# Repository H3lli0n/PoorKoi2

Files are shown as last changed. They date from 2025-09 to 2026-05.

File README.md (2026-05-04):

# PoorKoi2

Hi, HLB team Here !

In 2024 we ran our first public group-buy with the PoorKoi 1, an acrylic stacked keyboard. 30 happy users were very surprised by the clack of this simple 60% made with love. This was our first project, mistakes were made, but we learned a lot and we got confident that we could push even further: having the same thing in a cnc'd polycarbonate version!

We are aiming for the same clack and feeling with the polycarbonate version – with an affordable price. No brass weight or copper that are expensive if you don't sell 200 units. Simple design with references of the v1.

We had to make a stand between affordability and customization with a trusty and high quality manufacturer – DDS while upgrading our game : laser cut Poron gaskets, custom carrying case, in house hotswap pcb (as well as new solder one) !

You can find us on [Discord](https://discord.gg/ZV8Ysf6buB)

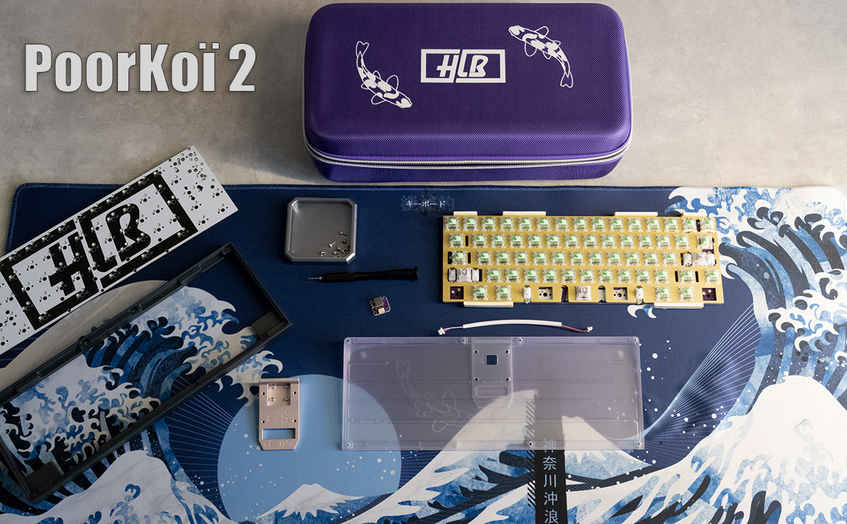
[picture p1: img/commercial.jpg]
PoorKoi 2


## Specifications
- 60% Poron gasket mount
- 7° typing angle
- WK/WKL/HHKB
- Polycarbonate bottom with central aluminium part
- Brass plate
- Geon feet D7
- 1.6mm HS/Solder PCB
  - RGB underglow
  - Capslock / layers indicator
- Unified DB C5
- Geon Venom HE compatible with standard plate
- EC60x EC compatible (Bakeneko JST position) with dedicated plates (see Files section)

Without feet:
- 18mm front height
- 23mm EKH

Weight full built (aluminium top)= 950gr

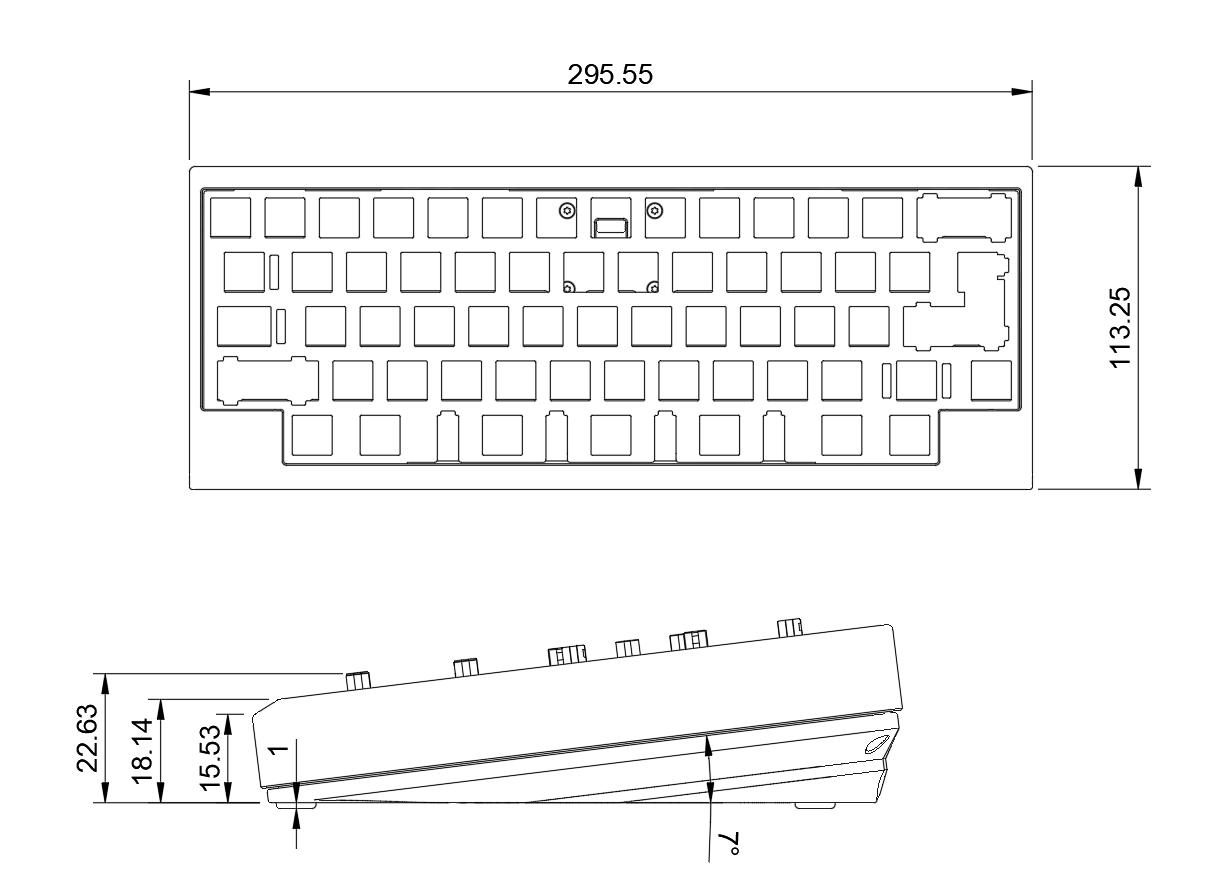
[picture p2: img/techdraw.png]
TechSpecs

You can find and share this [PDF Tech view](files/PoorTechView.pdf)

## What is included ?
- 1 x Carrying case
- 1 x PoorKoi v2 case
- 1 x Hotswap purple pcb
- 1 x Unified Daughter Board C5
- 1 x JST cable
- 1 x Plate foam
- 1 x Brass plate
- 1 x Bag of Geon D7 feet
- 2 x Bags of laser cut gaskets
- Screws

## Compatibility
- Hotswap
Layouts
- Solder
Layouts

## Project's status
### When
> First renders => done

> Keyboard prototypes => done

> PCB prototypes => done

> GeekHack IC => done

> Group-buy => Estimated end of May / Start of June

### Changelog
February 2026
- Standard plate is now Geon Venom HE compatible
- We added EC60X compatibility with dedicated ANSI plates

December 2025
- HLB60 is now our standard pcb and koï fishes are removed from the back
- Polycarbonate bottom will have 2 koï fishes like the carrying case

### Colors
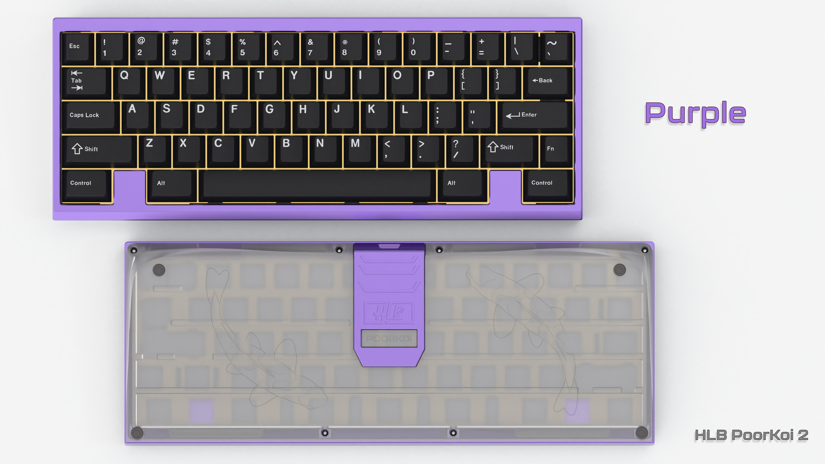
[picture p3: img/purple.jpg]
Purple

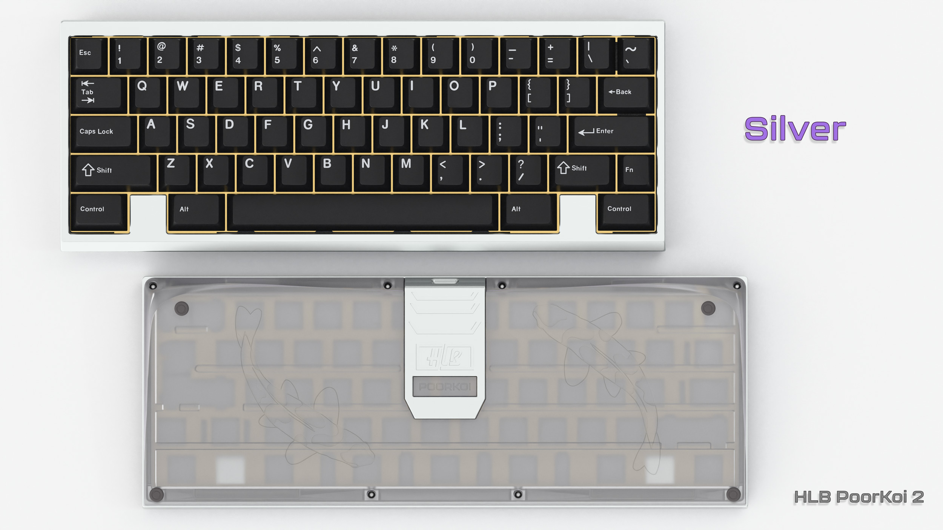
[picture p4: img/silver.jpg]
Silver

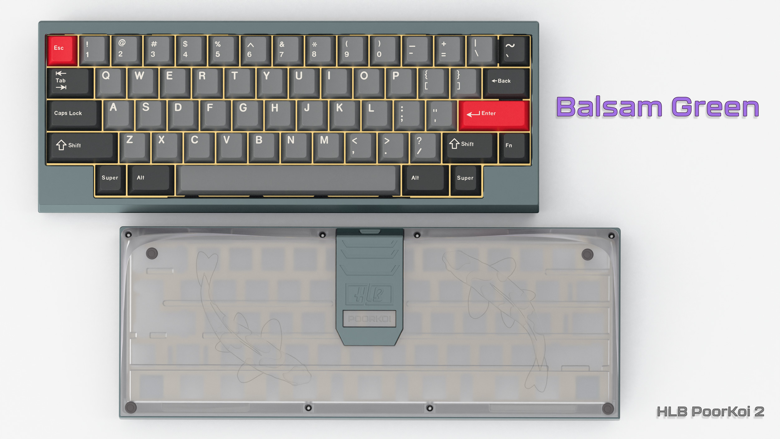
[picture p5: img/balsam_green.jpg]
BalsamGreen

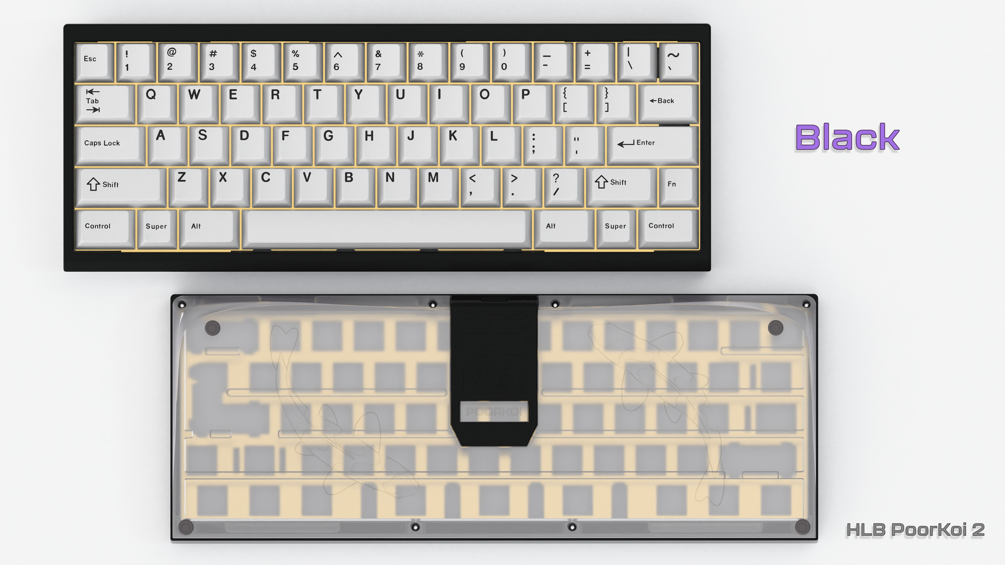
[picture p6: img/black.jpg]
Black

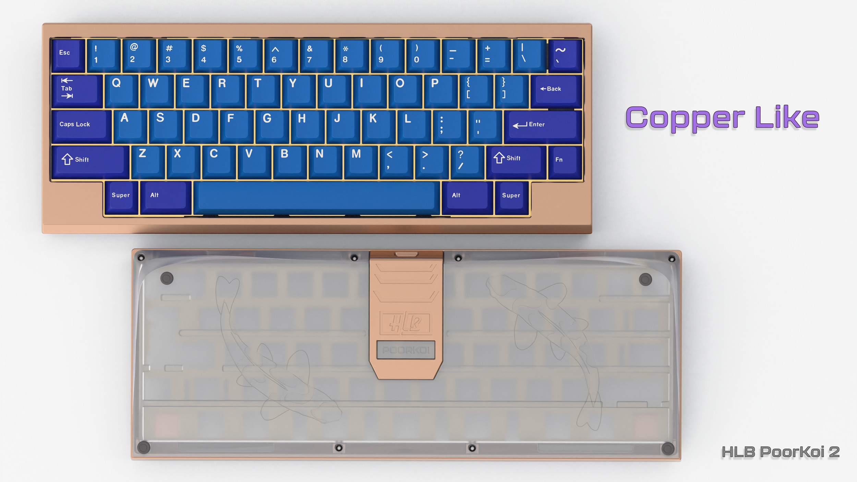
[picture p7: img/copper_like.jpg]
Copper Like


## Prototypes
Prototypes were ordered with the following GB colors :
- Purple (WK prototype)
- Silver (WK prototype)
- Balsam green (HHKB prototype)
- Copper like (WKL prototypes)
- Full Polycarbonate (WK prototype)

You can find pictures and sound test by clicking on the picture below.
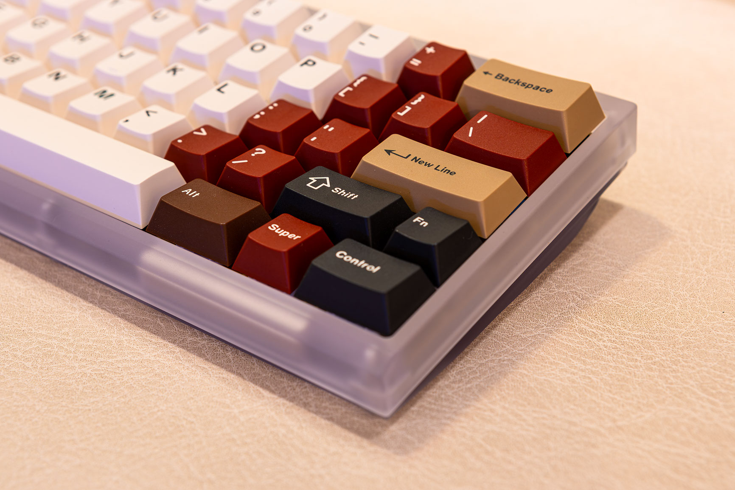
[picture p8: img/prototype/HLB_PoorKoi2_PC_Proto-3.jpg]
HLB PoorKoi 2 multimedia content (https://www.oliversphotoblog.com/2025/12/07/hlb-poorkoi-2/ "Go to multimedia content")


## Files
### Build Guide
You can find a simple build guide PDF [Build Guide v1](files/PoorKoi2_Build_Guide.pdf)

### Plate
Solder PCB supports full length right shift as well as 10U spacebar with 8U stabilizer.
You can find 2 versions, the one from base kit and the one with extended compatibilities, both are compatible with PoorKoi v1

- [Standard plate no HE](files/plate_brass.step)
- [Standard plate with HE](files/plate_he_compatible.step)
- [EC60x standard ansi plate](files/plate_ec60x_standard_7u_ansi.step)
- [EC60x split backspace ansi plate](files/plate_ec60x_splitbs_7u_ansi.step)

*Extended will be online later*

### Firmware
You can find documentation and firmware on the dedicated page [HLB60 doc](https://github.com/H3lli0n/HLB-Projects?tab=readme-ov-file#hlb60)

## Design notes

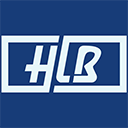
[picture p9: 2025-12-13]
img/hlbemot.png

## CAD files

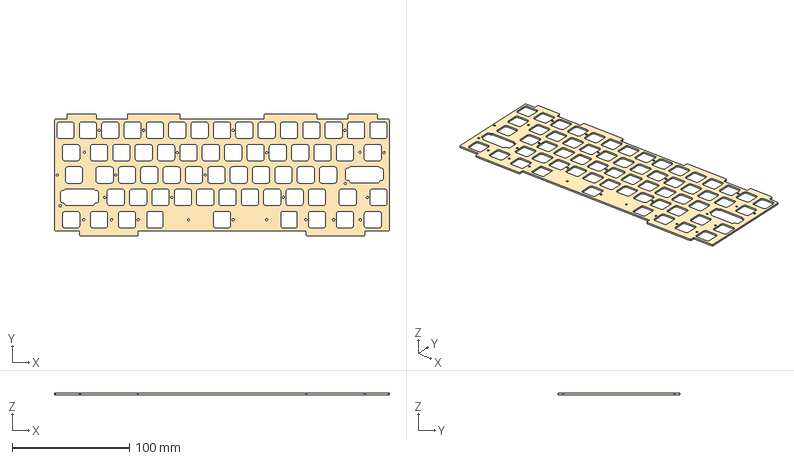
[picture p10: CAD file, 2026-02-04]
files/plate_ec60x_splitbs_7u_ansi.step
285.6 x 104.3 x 1.50 mm

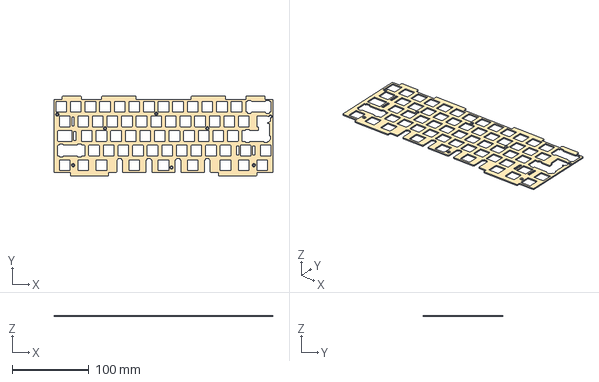
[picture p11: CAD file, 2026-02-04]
files/plate_he_compatible.step
285.6 x 104.3 x 1.50 mm

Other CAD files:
files/plate_ec60x_standard_7u_ansi.step
files/plate_brass.step

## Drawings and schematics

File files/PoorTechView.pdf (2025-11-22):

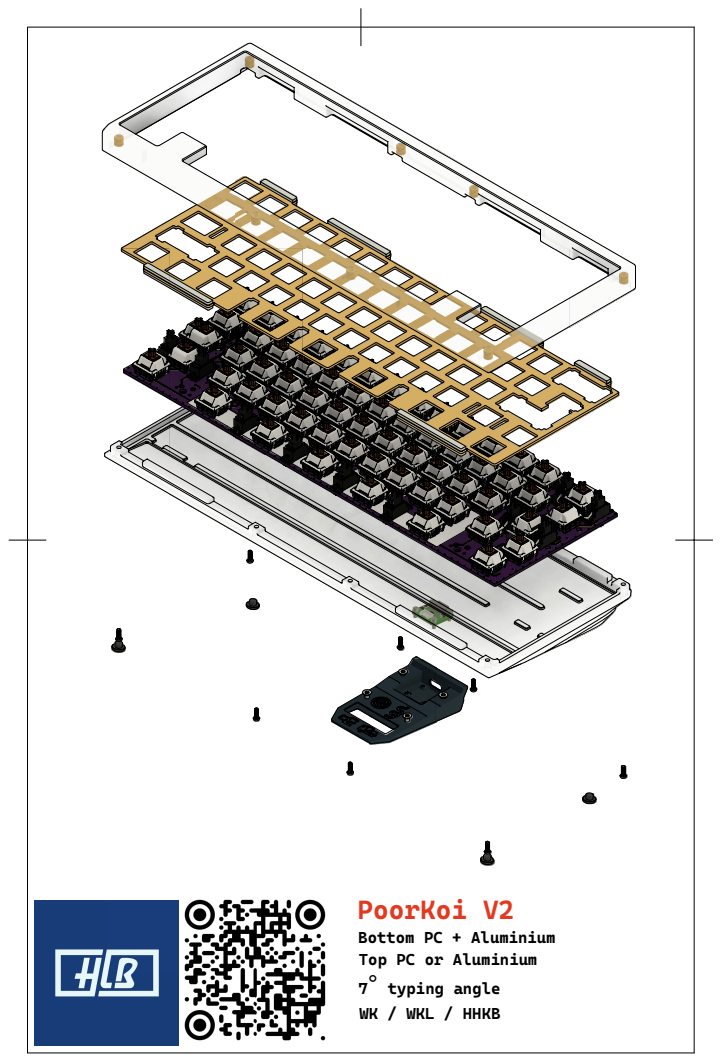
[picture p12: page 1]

PoorKoi V2
Bottom PC + Aluminium
Top PC or Aluminium
° typing angle
WK / WKL / HHKB

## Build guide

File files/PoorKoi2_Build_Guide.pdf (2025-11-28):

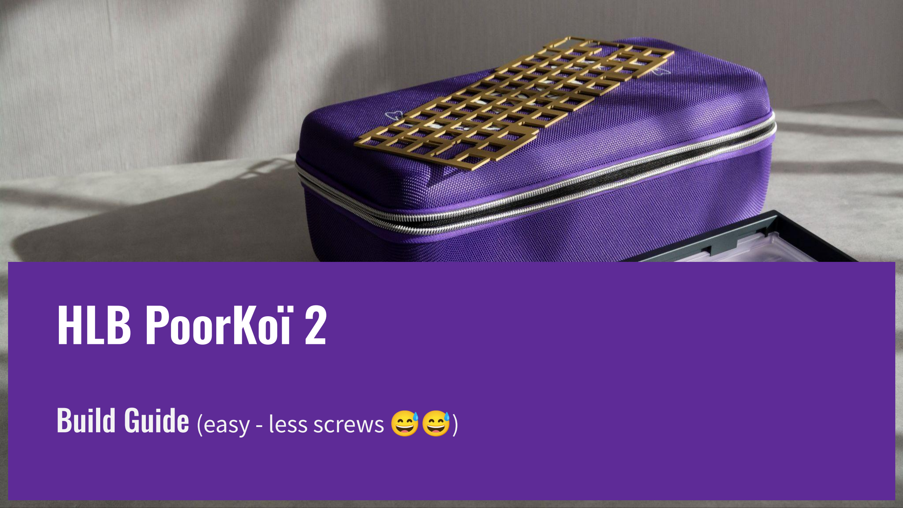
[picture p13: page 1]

# HLB PoorKoï 2

Build Guide (easy - less screws 😅😅)

# JST / Daughterboard

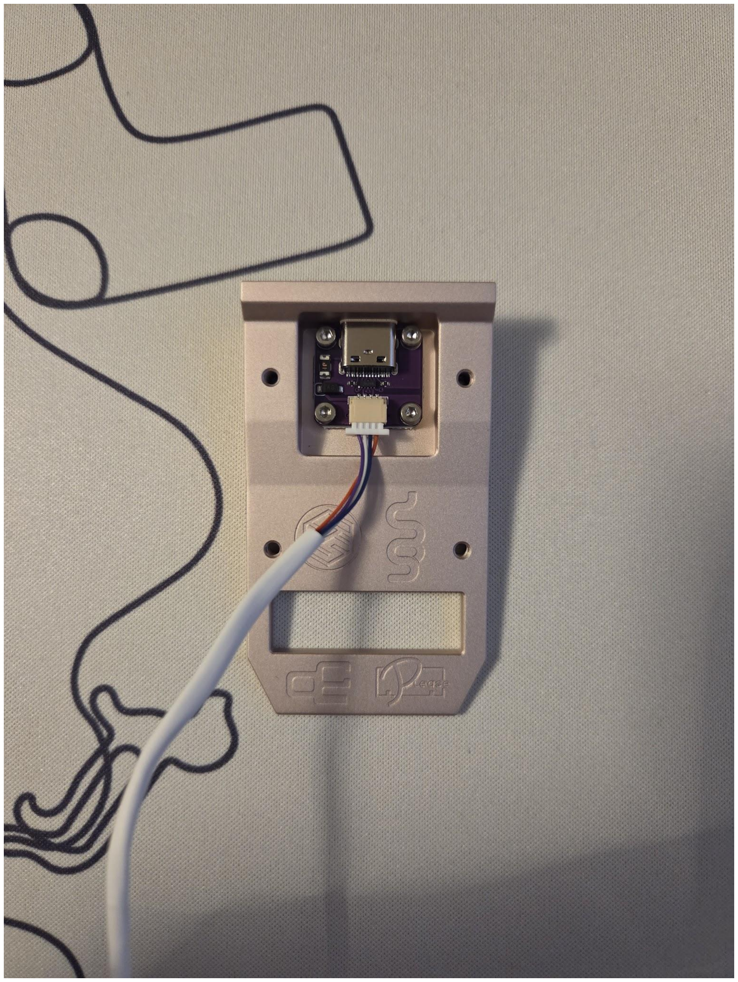
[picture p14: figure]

- If you have a JST cable with heat shrink we recommend you to have it shrinked (just use a hair dryer) - cable will take less space and will more gentle to work with
- Connect JST to DB
- Screw DB in the aluminium center part

PoorKoï 2 - build guide

# Install center part

- Install polycarbonate bottom on the aluminium part
- Use the hole for jst cable

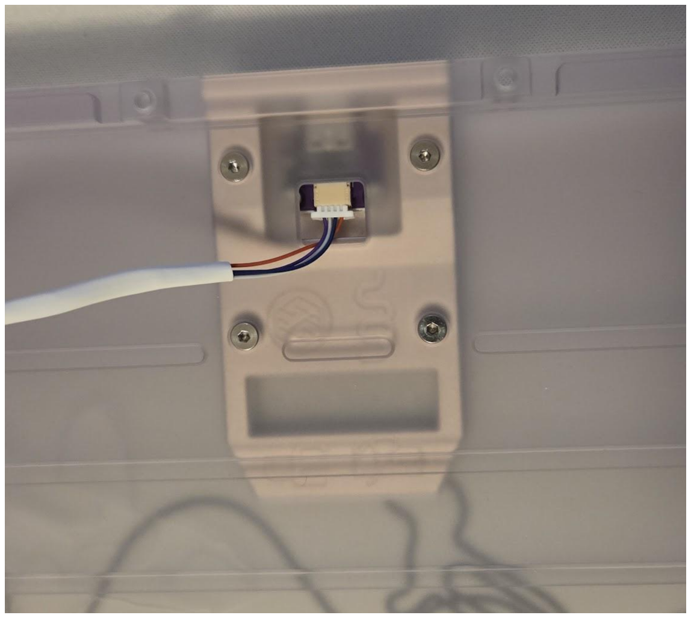
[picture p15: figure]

✘DONʼT OVER TIGHT THE SCREWS

# Plate / PCB

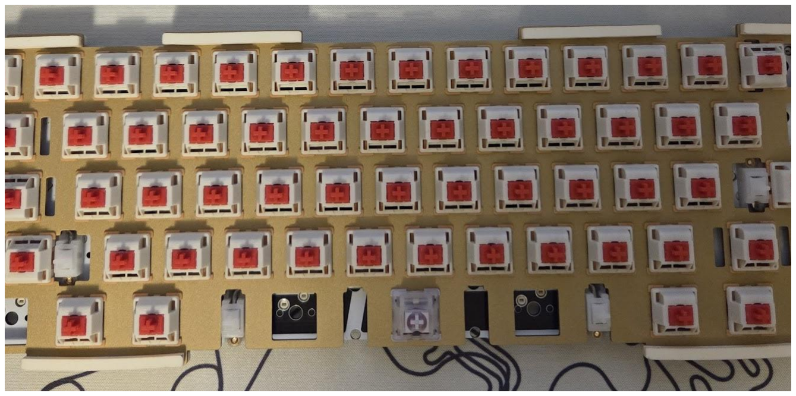
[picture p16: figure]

- You have 2 bags of gaskets, you can
- Install them on the plate
- Install them on the case
- There are 3 dimensions
- The largest on bottom
- Once installed connect jst cable to pcb
- Install pcb on the bottom part
- Push jst on the back so it can be straight

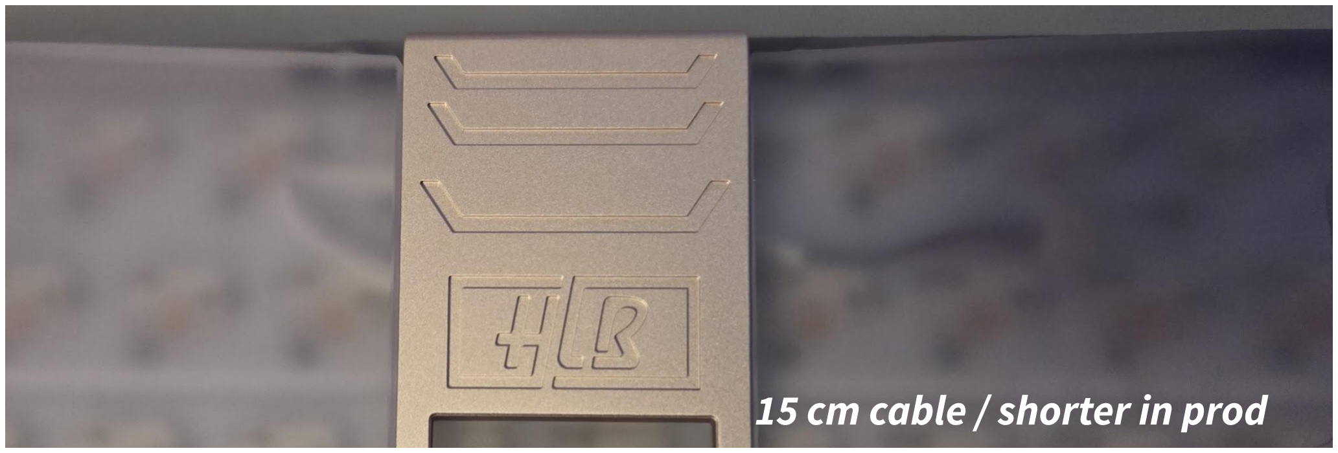
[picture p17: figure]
15 cm cable / shorter in prod

# Finish and enjoy 😎

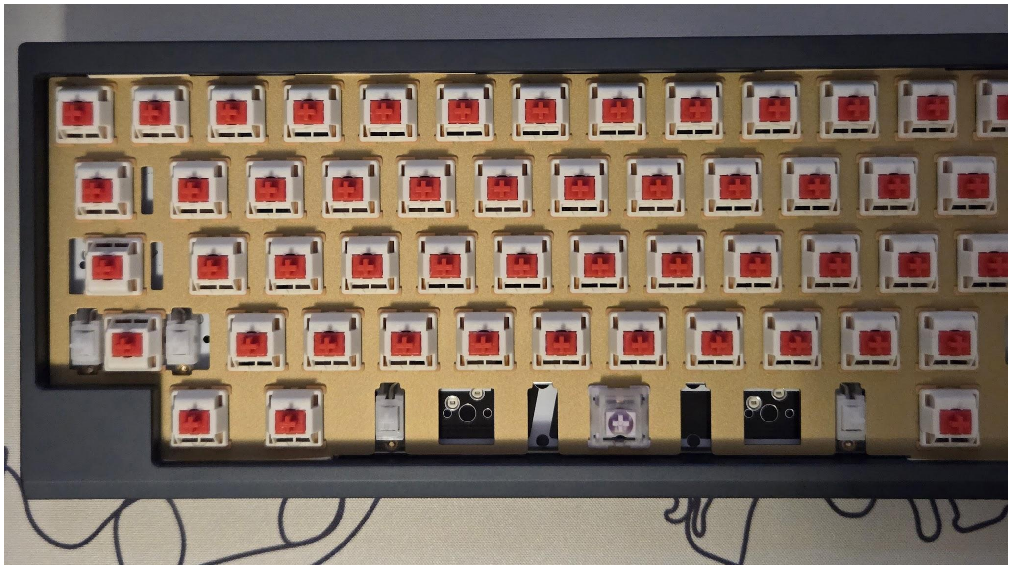
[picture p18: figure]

- Put the top frame
- Flip the keyboard
- Close the case with screws
- Add the feet

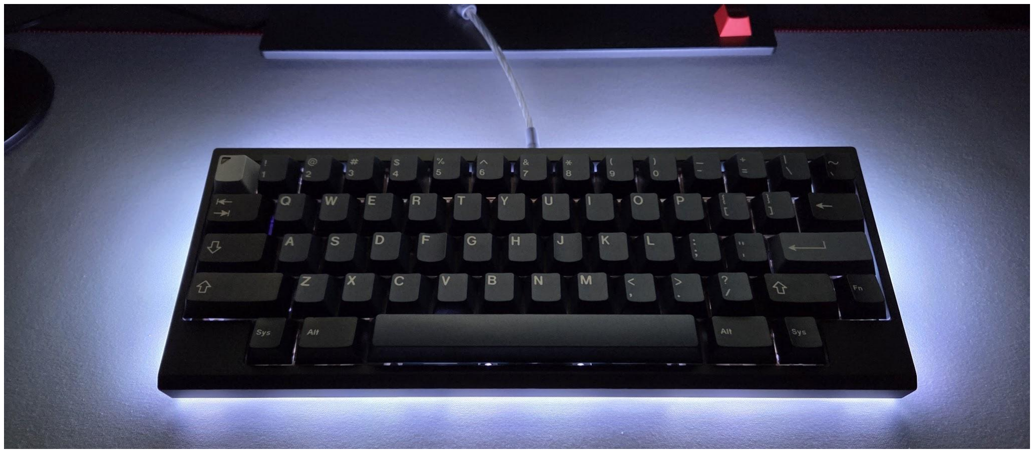
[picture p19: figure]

✘DONʼT OVER TIGHT THE SCREWS

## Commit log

2025-09-28 fix: renders and description
    [plate_brass.step]
2025-11-22 feat: adding prototype material
2025-11-25 feat: link to pcb documentation
2025-12-13 fix: render camera
2026-02-04 feat: updates
    [plate_ec60x_splitbs_7u_ansi.step, plate_ec60x_standard_7u_ansi.step, plate_he_compatible.step]
